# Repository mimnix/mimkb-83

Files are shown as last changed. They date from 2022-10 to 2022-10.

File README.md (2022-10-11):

# MIMKB-83: Fully 3D printed DIY ISO 75% handwired mechanical keyboard powered by Raspberry Pi Pico
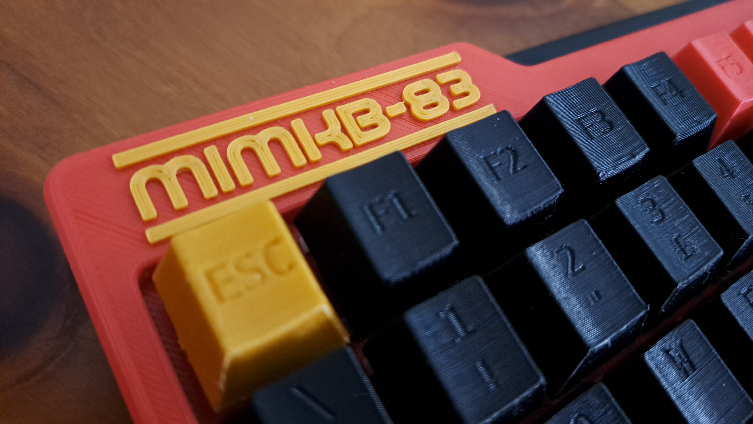
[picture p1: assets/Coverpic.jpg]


The keyboard is fully customizable, it supports layering, macros, dynamic sequences, and chords. The possibilities are endless. The project includes:

- Building instructions
- 3d model of the body of the keyboard
- 3d models of KeyV2 generated keycaps (default: ISO-ITA with Cherry profile)
- Wiring instructions
- Firmware source code for the Raspberry Pi Pico

## Features
The firmware is implemented to provide basic keyboard features and plus:

**Media keys**
- Fn + F1 = Mute audio
- Fn + F2 = Audio volume down
- Fn + F3 = Audio volume up

**Dynamic sequences (macros)**
- Fn + 1,2,...,0 = Select sequence slot
- Fn + F5 = Record sequence in the current slot
- Fn + F6 = Stop recording sequence in the current slot
- Fn + F7 = Play the sequence of the current slot

## Bill of materials and cost breakdown
You're supposed to have access to a 3D printer with some PLA spools. A PLA spool costs around 18-20€
For this build I've used:
- PLA plastic (18€)
- 90x Outemu Silent Peach linear switches (25€)
- Raspberry Pi Pico (7€)
- 200x 1N4148 Diodes (1,7€)
- 100x 8x2.5mm rubber feet (2€)
- Costar stabs (4,8€)
- Copper wire (2,7€)
- 12x M3x12mm screws (some cents)
- Some 22awg wire (some cents)
- Optional: Krytox GPL 205 lube because you love custom keyboards and lube switches and stabs, don't you?

**Total cost: 61,2€** and you will get a lot of remaining material available for other builds.

## Body parts
Navigate to the `model/body/STL` folder and print one copy of each file. You have 5 body parts in total: 2 pieces for the plate (`Top_left_iso` and `Top_right_iso`), 2 pieces for the housing (`Bottom_left` containing the microcontroller slot and `Bottom_right`), 
1 set of `Dowels` to keep all the pieces joined together and harden the structure. Import the files in your favorite slicer (Prusa slicer, Ultimaker Cura, etc...) and produce the gcode files. The prototype has been printed using the following settings:

- Printing material: PLA
- Standard quality (layer height 0.2mm, walls width 0.8mm with 2 perimetral lines, printing speed 50mm/s)
- Bed temperature: 60°C (it depends on the specific material)
- Extruder temperature: 200°C (it depends on the specific material)
- Infill: 20%
- 5mm of brim, around 13 lines just to avoid any warping effect
- no supports, they're not needed

Once all the parts are printed, glue and connect the two top half sectors and the two bottom half sectors, that's it.

## Keycaps
Navigate to the `model/body/keycaps/STL` folder and print everything. Prebuilt keycaps are for the 75% ISO-ITA layout, if you need advanced customization, please refer to the [advanced customizations](#advanced-customizations) section. You will find printable keycap groups with legends (filenames are pretty self-explanatory). You can use the same slicer configuration as the body parts, just consider placing the keycaps with the southern surface facing the bed plate, screenshot for reference:

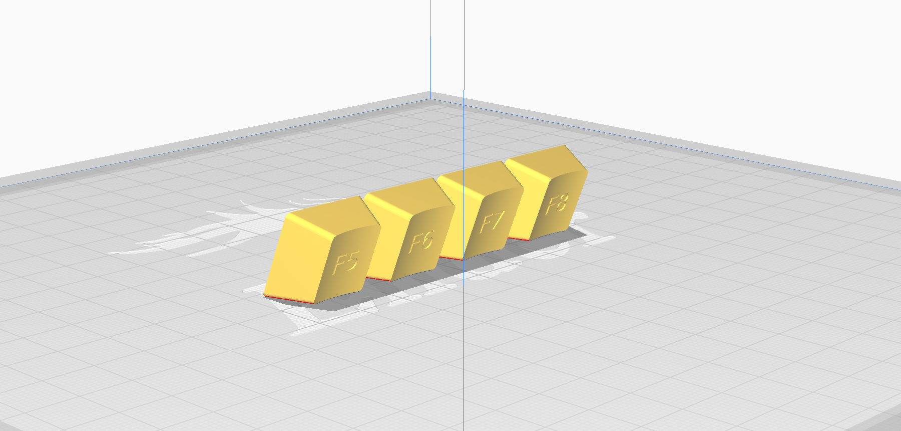
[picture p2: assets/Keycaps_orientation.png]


## Wiring instructions
Here comes the ~~boring~~ fun part. First thing first, take the 3d printed plate and snap your favorite mechanical switches into it.

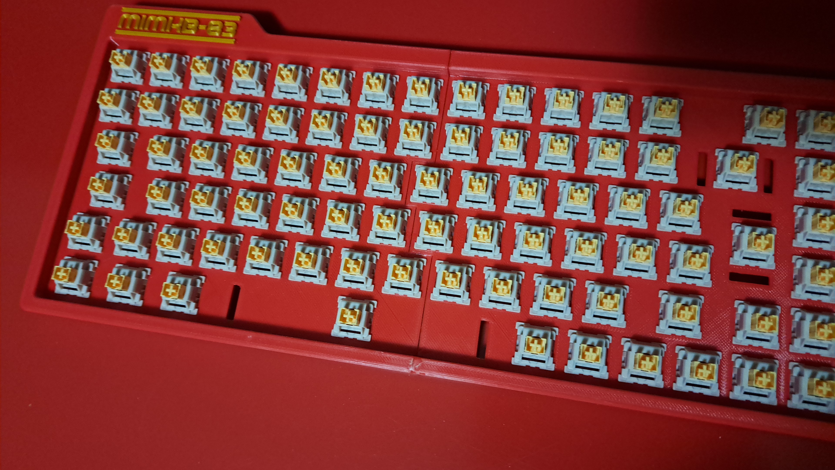
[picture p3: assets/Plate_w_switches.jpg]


Turn over the plate, take the diodes and bend'em from the cathode side in this way:

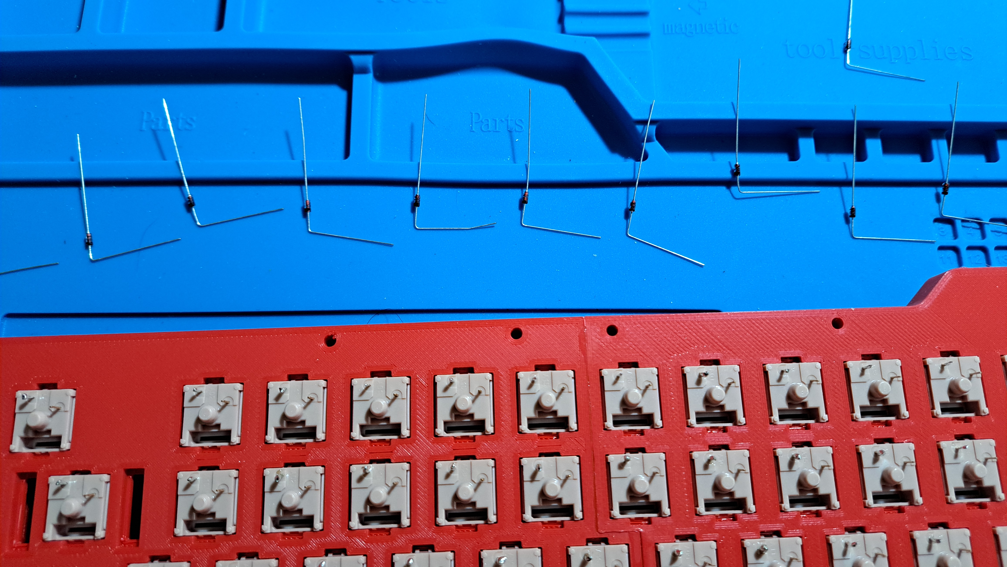
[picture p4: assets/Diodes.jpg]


Solder each anode to the leftmost pin of the switches, and the cathode to the next diode's cathode to create a row:

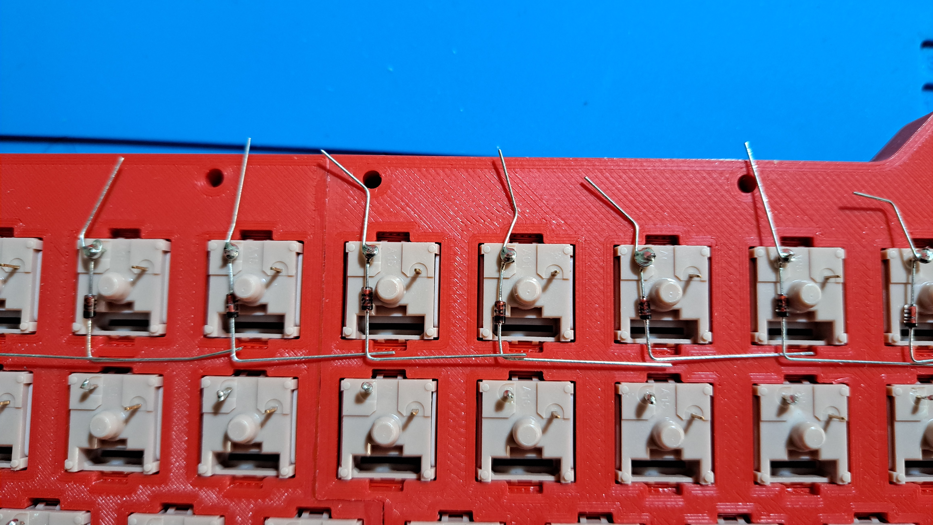
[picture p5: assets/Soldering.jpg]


Snap the exceeding metal terminals and everything will look like this:

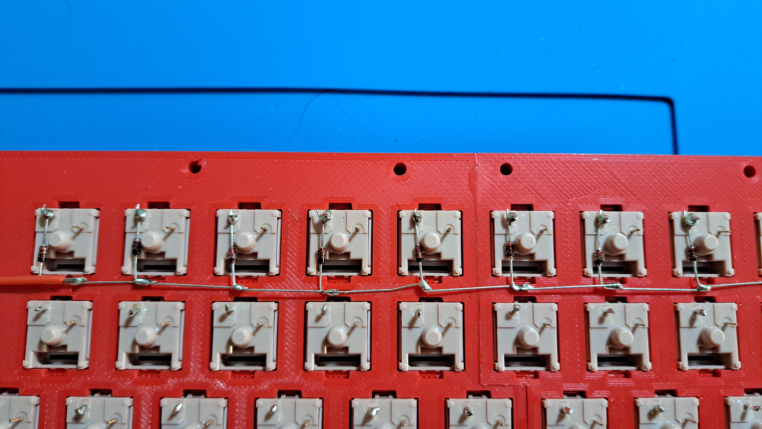
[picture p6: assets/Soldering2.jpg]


Repeat for all the rows and isolate them using electrical tape stripes. Then, solder the columns using some 0.5mm copper wire: connect the right pin of all the switches in the same column, like in the picture below:

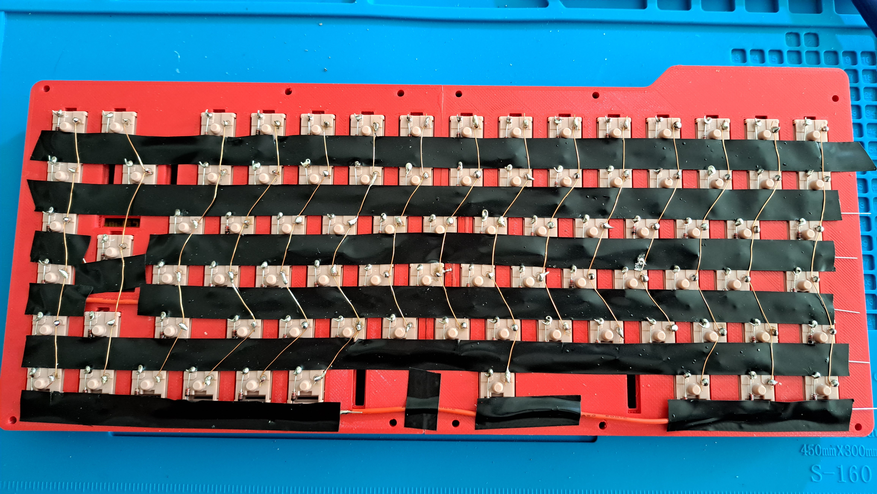
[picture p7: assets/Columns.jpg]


Now, time to connect the switch matrix to the Raspberry Pi Pico board according to the following wiring diagram:

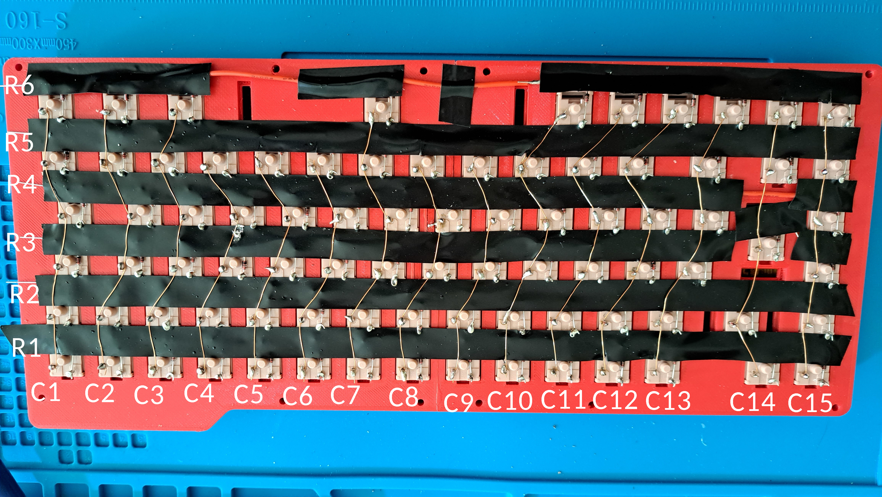
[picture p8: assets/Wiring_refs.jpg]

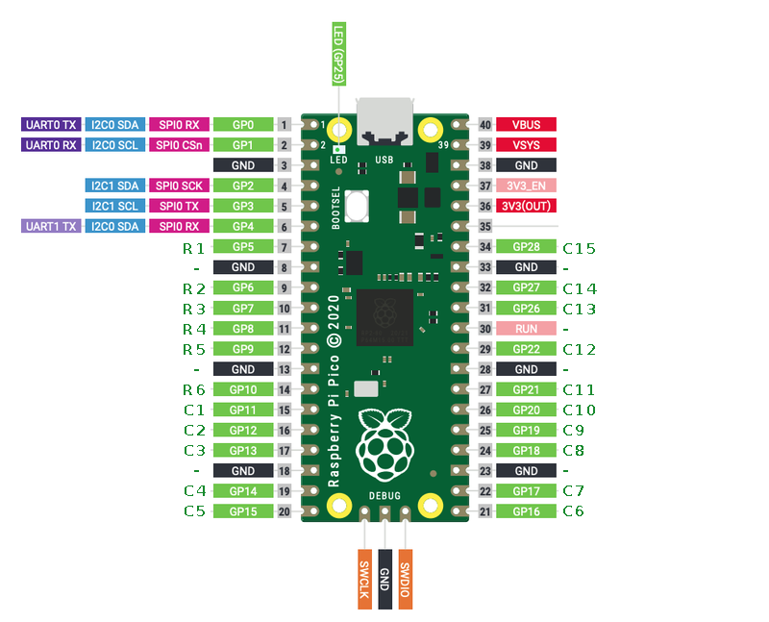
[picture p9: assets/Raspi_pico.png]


This is how it should look like:

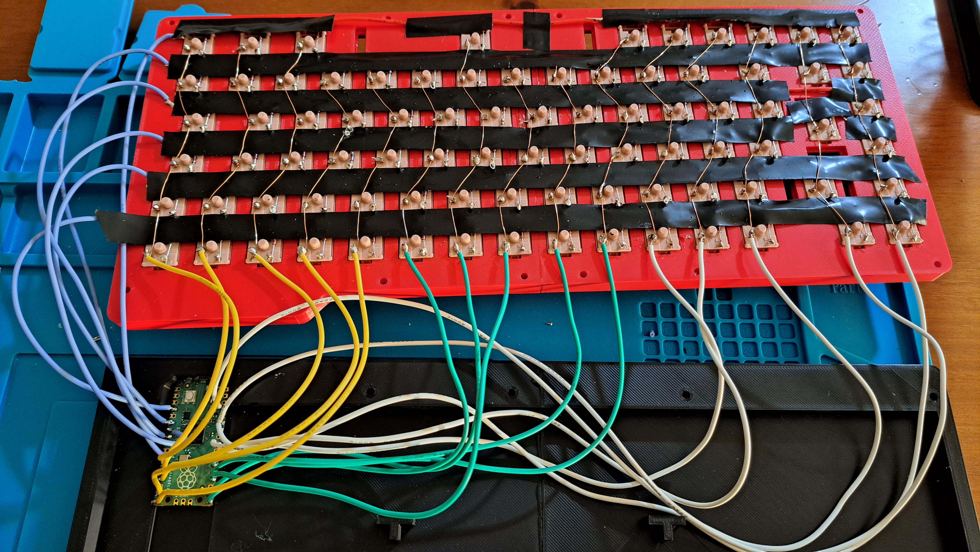
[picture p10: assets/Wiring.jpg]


And here's the PCB closeup:

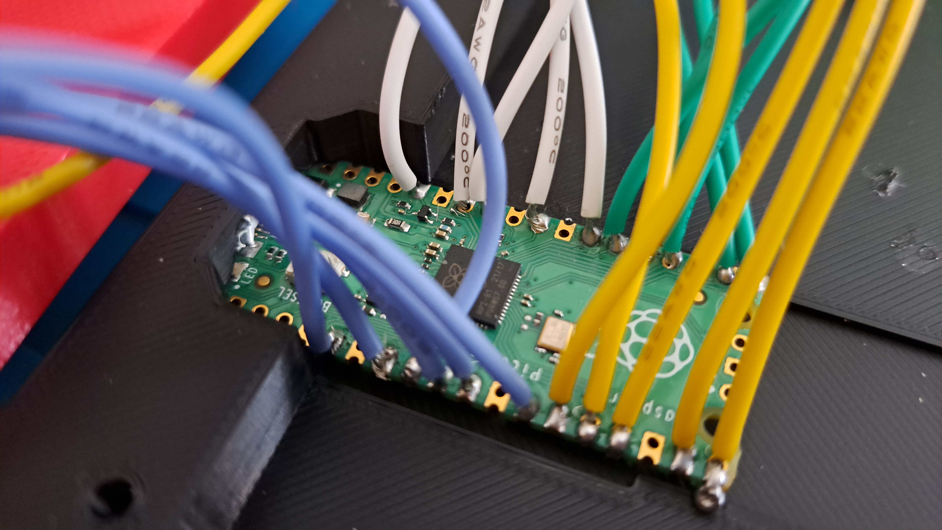
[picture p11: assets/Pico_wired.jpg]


Place the Raspberry Pi Pico in its slot, and fix it using a hot glue gun. The glue protects the cables and sticks the Raspberry pi pico in place. Close the keyboard and screw the plate and the housing together using 12mm M3 bolts, stick four 8x2.5mm rubber feet on the bottom surface of the keyboard snap the stabilizers in their slots, snap the keycaps on top of the switches and with the hardware you're pretty good to go.

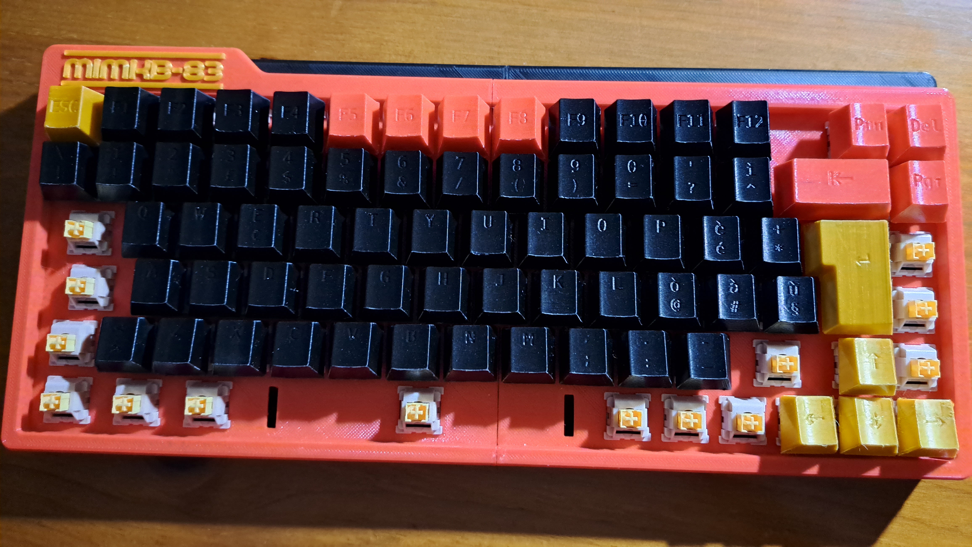
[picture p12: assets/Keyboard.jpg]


## Firmware
4 simple steps:
1. Connect the keyboard to the PC.
2. Install [CircuitPython](https://learn.adafruit.com/welcome-to-circuitpython/installing-circuitpython) version 7.0 or above in the Raspberry Pi Pico.
3. Install [KMK](https://github.com/KMKfw/kmk_firmware/blob/master/docs/Getting_Started.md) in the board.
4. Replace the `code.py` file of the board with the one provided in the directory `firmware` of this project.

**Happy typing!**

## Advanced customizations
You can customize pretty much everything, the possibilities are endless. Install OpenSCAD on your PC, open the file `model/keycaps/KeyV2/keys.scad`. It's the layout definition of Mimkb-83. From there, you can edit legends and every possible feature such as height, stems, profiles, and so on. The most important files are two:

- `model/keycaps/KeyV2/keys.scad` to edit the layout and the keyboard profile (default: cherry/GMK)
- `model/keycaps/KeyV2/settings.scad` to edit stem type (default: rounded cherry), support type, sizes, and all the physical aspects of the keycaps.

For more info about keyboard profiles, have a look at [keycaps.info](https://keycaps.info).

You can also modify the firmware according to the [KMK documentation](http://kmkfw.io/)

## Credits
This project is based on and inspired by the work of some makers and developers out there. They provided their code to the world. A deserved shoutout to:

- [SICK-68 keyboard](https://www.thingiverse.com/thing:3478494) by FedorSosnin
- [The Raspberry Pi Pico](https://www.raspberrypi.com/products/raspberry-pi-pico/) open hardware board by the Raspberry Pi Foundation
- [KMKfw](http://kmkfw.io/) the pythonic keyboard firmware
- Bob rsheldii's [KeyV2](https://github.com/rsheldiii/KeyV2), a parametric mechanical keycap library

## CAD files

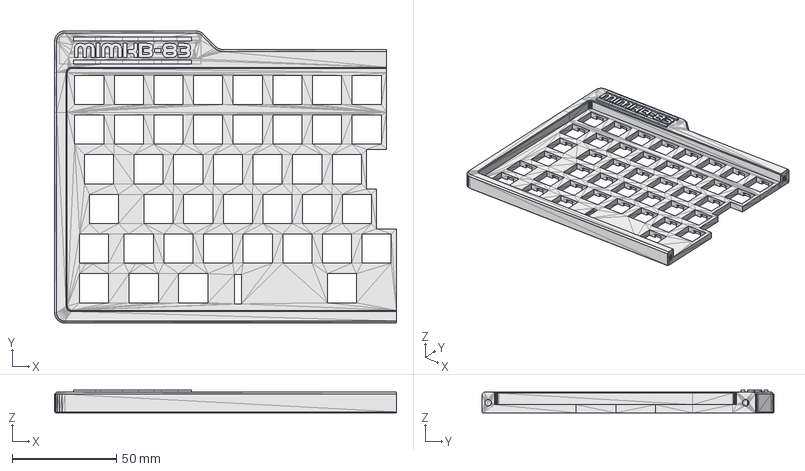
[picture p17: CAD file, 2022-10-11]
model/body/Mimboard.FCStd
164.3 x 140.4 x 11.0 mm

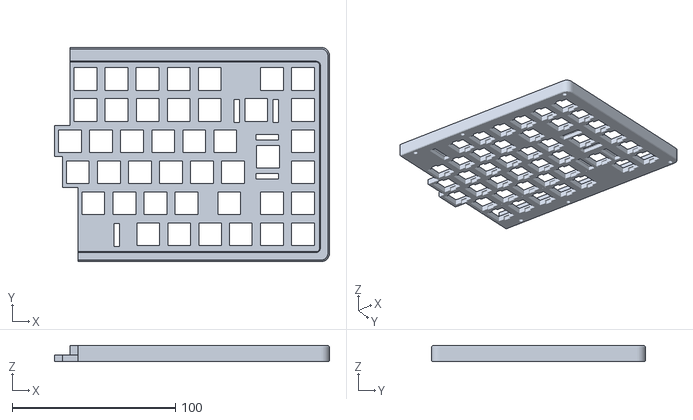
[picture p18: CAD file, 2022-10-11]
model/body/STL/Top_right_iso.stl
168.7 x 131.4 x 10.0

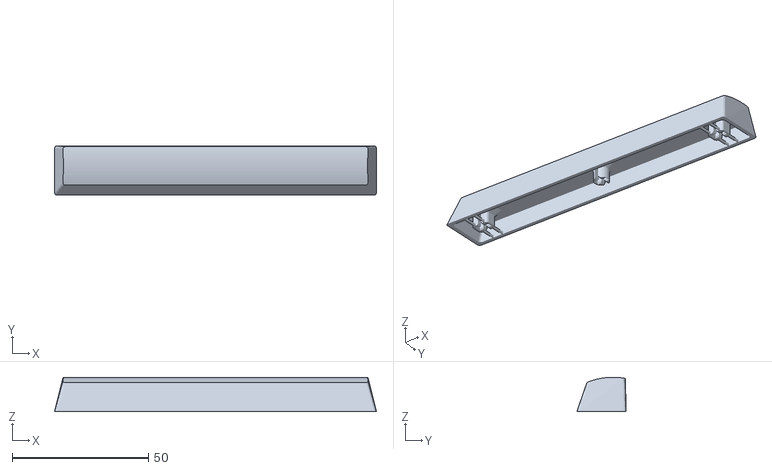
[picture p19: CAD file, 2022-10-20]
model/keycaps/STL/Spacebar.stl
118.2 x 18.2 x 12.6

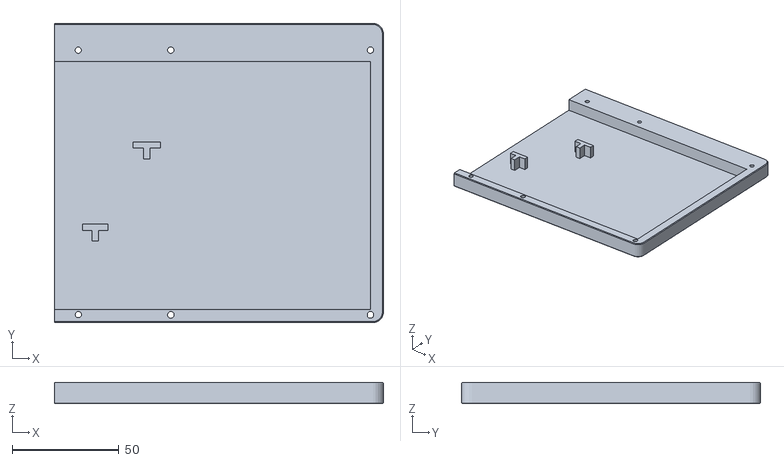
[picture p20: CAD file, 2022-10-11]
model/body/STL/Bottom_right.stl
154.3 x 140.4 x 10.0

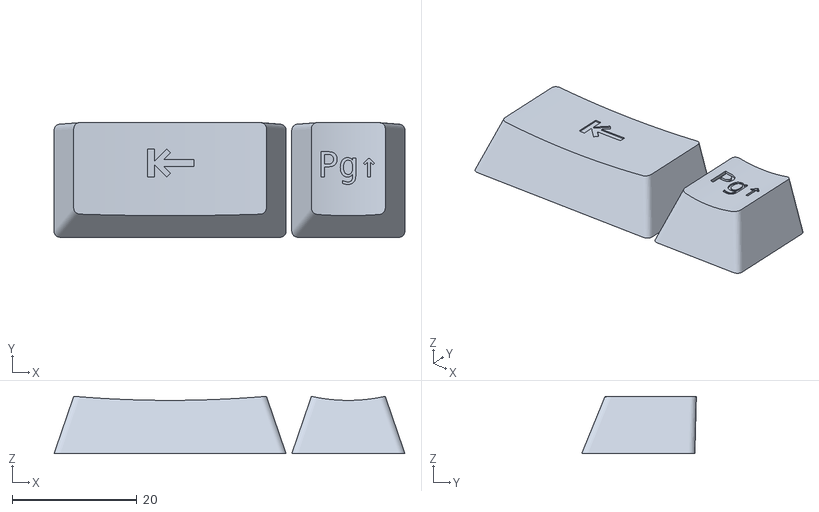
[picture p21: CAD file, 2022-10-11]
model/keycaps/STL/Keys Backspace PageUp.stl
56.3 x 18.4 x 9.20

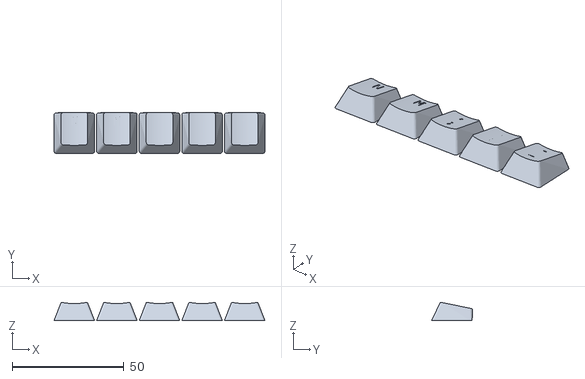
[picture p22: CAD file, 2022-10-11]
model/keycaps/STL/Keys row2 2of2.stl
94.4 x 18.3 x 8.10

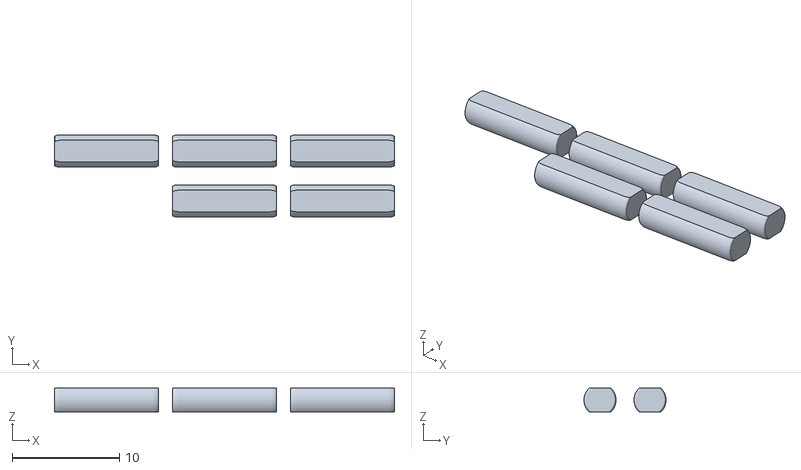
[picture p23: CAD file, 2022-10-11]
model/body/STL/Dowels.stl
31.7 x 7.66 x 2.21

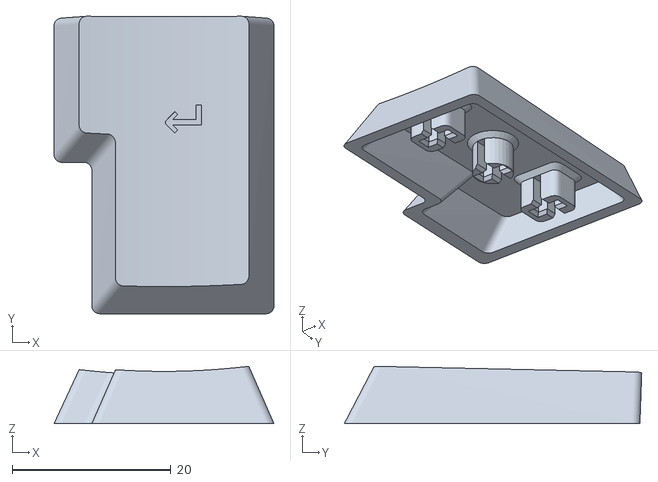
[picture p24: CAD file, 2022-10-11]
model/keycaps/STL/Keys Enter.stl
27.7 x 37.4 x 7.20

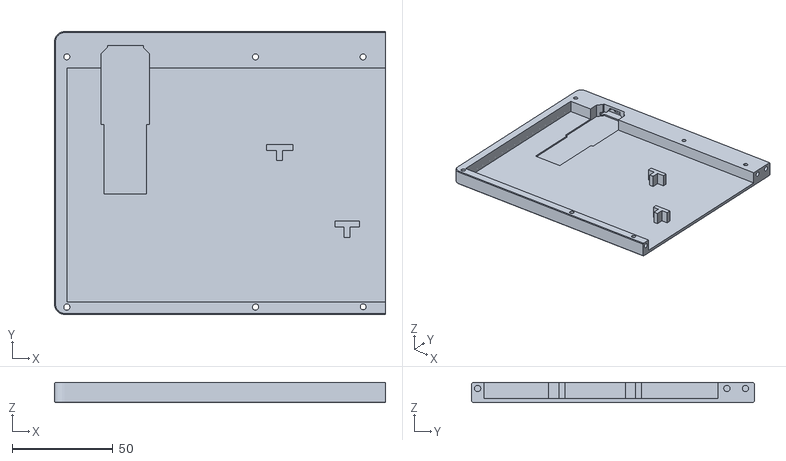
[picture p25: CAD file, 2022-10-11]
model/body/STL/Bottom_left.stl
164.3 x 140.4 x 10.0

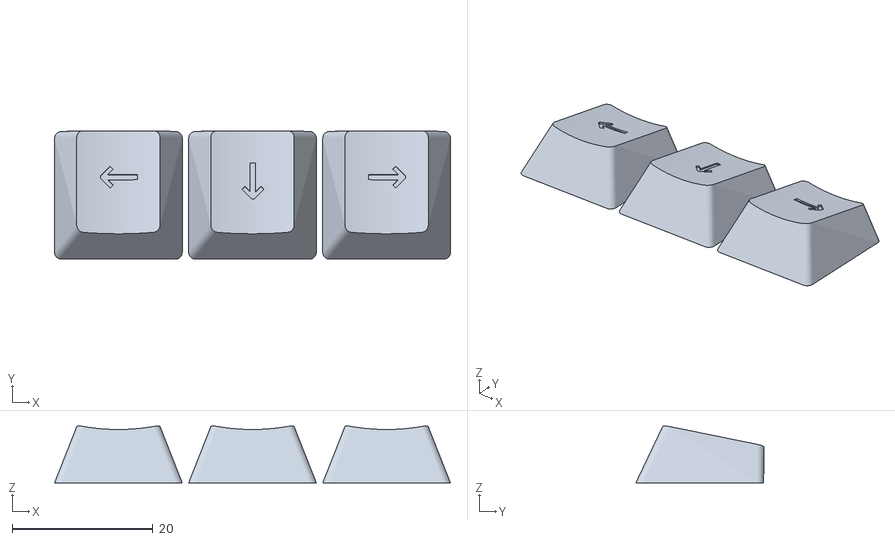
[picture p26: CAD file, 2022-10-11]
model/keycaps/STL/Keys Arrow Left Down Right.stl
56.3 x 18.3 x 8.10

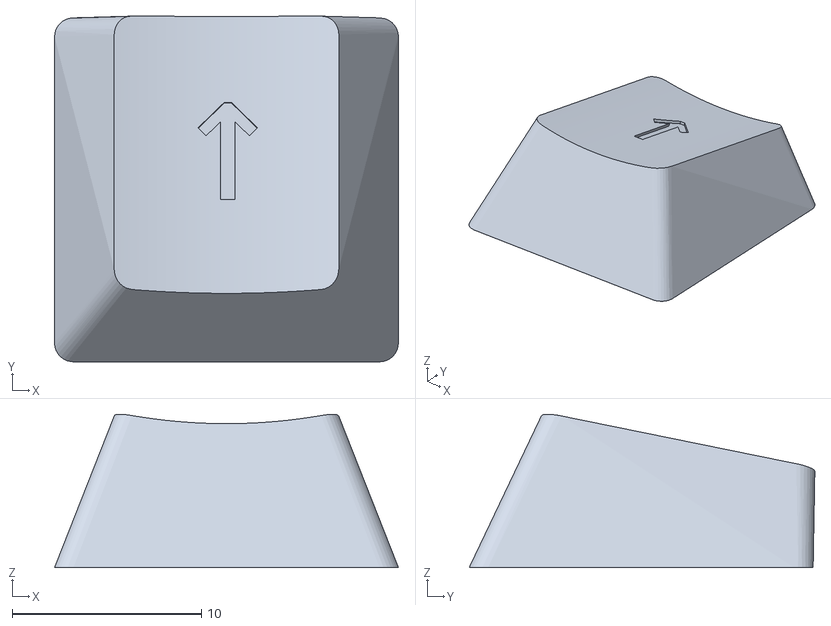
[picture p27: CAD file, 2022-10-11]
model/keycaps/STL/Keys Arrow Up.stl
18.2 x 18.3 x 8.10

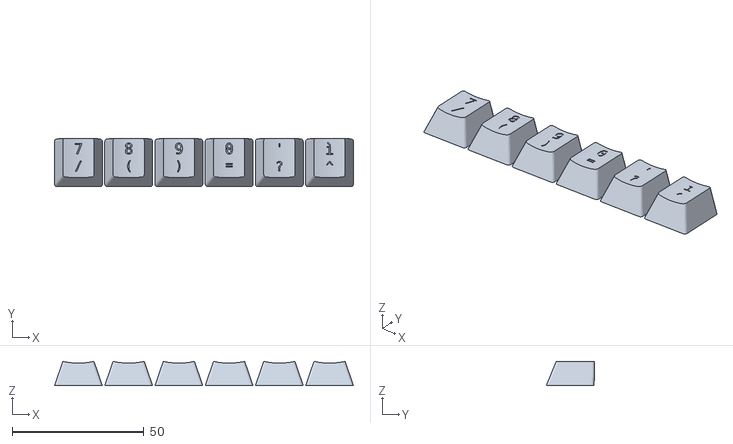
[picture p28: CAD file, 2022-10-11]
model/keycaps/STL/Keys row5 2of2.stl
113.4 x 18.4 x 9.20

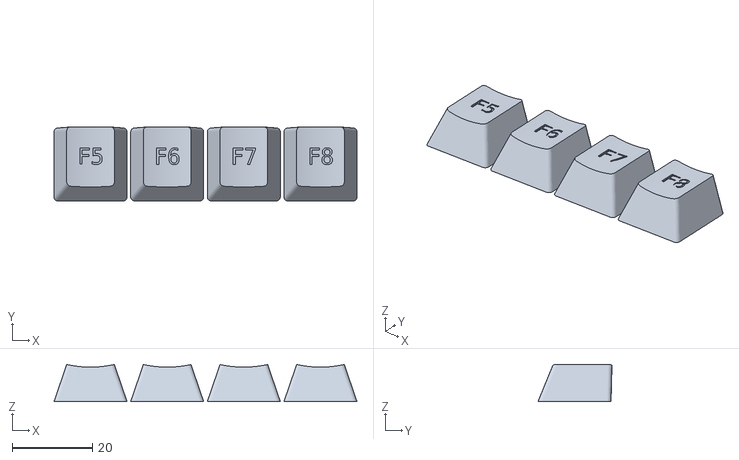
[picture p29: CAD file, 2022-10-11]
model/keycaps/STL/Keys F5-F8.stl
75.3 x 18.4 x 9.20

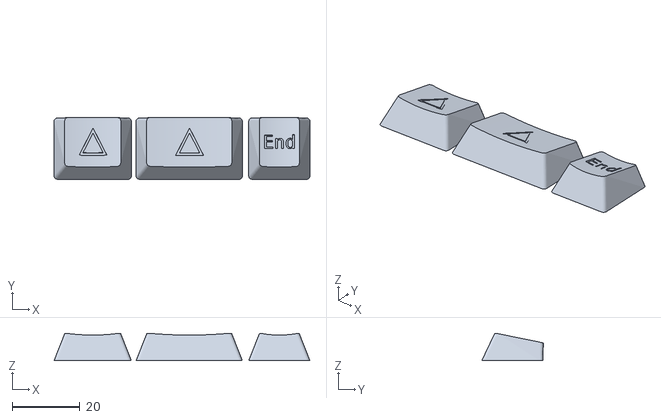
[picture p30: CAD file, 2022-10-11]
model/keycaps/STL/Keys Lshift Rshift End.stl
75.8 x 18.3 x 8.14

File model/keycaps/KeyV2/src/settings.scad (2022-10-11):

/* [Basic-Settings] */

// Length in units of key. A regular key is 1 unit; spacebar is usually 6.25
$key_length = 1.0; // Range not working in thingiverse customizer atm [1:0.25:16]

// What type of stem you want. Most people want Cherry.
$stem_type = "rounded_cherry";  // [cherry, alps, rounded_cherry, box_cherry, filled, disable]

// The stem is the hardest part to print, so this variable controls how much 'slop' there is in the stem
// if your keycaps stick in the switch raise this value
$stem_slop = 0.35; // Not working in thingiverse customizer atm [0:0.01:1]
// broke this out. if your keycaps are falling off lower this value. only works for cherry stems rn
$stem_inner_slop = 0.2;

// Font size used for text
$font_size = 6;

// Set this to true if you're making a spacebar!
$inverted_dish = false;

// change aggressiveness of double sculpting
// this is the radius of the cylinder the keytops are placed on
$double_sculpt_radius = 200;


// Support type. default is "flared" for easy FDM printing; bars are more realistic, and flat could be for artisans
$support_type = "flared"; // [flared, bars, flat, disable]

// Supports for the stem, as it often comes off during printing. Reccommended for most machines
$stem_support_type = "tines"; // [tines, brim, disabled]

// make legends outset instead of inset.
// broken off from artisan support since who wants outset legends?
$outset_legends = false;

/* [Key] */
// Height in units of key. should remain 1 for most uses
$key_height = 1.0;
// Keytop thickness, aka how many millimeters between the inside and outside of the top surface of the key
$keytop_thickness = 1;
// Wall thickness, aka the thickness of the sides of the keycap. note this is the total thickness, aka 3 = 1.5mm walls
$wall_thickness = 3;
// Radius of corners of keycap
$corner_radius = 1;
// Width of the very bottom of the key
$bottom_key_width = 18.16;
// Height (from the front) of the very bottom of the key
$bottom_key_height = 18.16;
// How much less width there is on the top. eg top_key_width = bottom_key_width - width_difference
$width_difference = 6;
// How much less height there is on the top
$height_difference = 4;
// How deep the key is, before adding a dish
$total_depth = 11.5;
// The tilt of the dish in degrees. divided by key height
$top_tilt = -6;
// the y tilt of the dish in degrees. divided by key width.
// for double axis sculpted keycaps and probably not much else
$top_tilt_y = 0;
// How skewed towards the back the top is (0 for center)
$top_skew = 1.7;

// how skewed towards the right the top is. unused, but implemented.
// for double axis sculpted keycaps and probably not much else
$top_skew_x = 0;

/* [Stem] */

// How far the throw distance of the switch is. determines how far the 'cross' in the cherry switch digs into the stem, and how long the keystem needs to be before supports can start. luckily, alps and cherries have a pretty similar throw. can modify to have stouter keycaps for low profile switches, etc
$stem_throw = 4;
// Diameter of the outside of the rounded cherry stem
$rounded_cherry_stem_d = 5.5;


// How much higher the stem is than the bottom of the keycap.
// Inset stem requires support but is more accurate in some profiles
// can be negative to make outset stems!
$stem_inset = 0;
// How many degrees to rotate the stems. useful for sideways keycaps, maybe
$stem_rotation = 0;

/* [Shape] */

// Key shape type, determines the shape of the key. default is 'rounded square'
$key_shape_type = "rounded_square";
// ISO enter needs to be linear extruded NOT from the center when not using skin. this tells the program how far up 'not from the center' is
$linear_extrude_height_adjustment = 0;
// How many slices will be made, to approximate curves on corners. Leave at 1 if you are not curving corners
// If you're doing fancy bowed keycap sides, this controls how many slices you take
$height_slices = 1;

/* [Dish] */

// What type of dish the key has. note that unlike stems and supports a dish ALWAYS gets rendered.
$dish_type = "cylindrical"; // [cylindrical, spherical, sideways cylindrical, old spherical, disable]
// How deep the dish 'digs' into the top of the keycap. this is max depth, so you can't find the height from total_depth - dish_depth. besides the top is skewed anyways
$dish_depth = 1;
// How skewed in the x direction the dish is
$dish_skew_x = 0;
// How skewed in the y direction (height) the dish is
$dish_skew_y = 0;


$dish_offset_x = 0;

// If you need the dish to extend further, you can 'overdraw' the rectangle it will hit. this was mostly for iso enter and should be deprecated
$dish_overdraw_width = 0;
// Same as width but for height
$dish_overdraw_height = 0;

/* [Misc] */
// There's a bevel on the cherry stems to aid insertion / guard against first layer squishing making a hard-to-fit stem.
$cherry_bevel = true;

// How tall in mm the stem support is, if there is any. stem support sits around the keystem and helps to secure it while printing.
$stem_support_height = .8;
// Font used for text
$font="DejaVu Sans Mono:style=Book";
// Whether or not to render fake keyswitches to check clearances
$clearance_check = false;
// Should be faster, also required for concave shapes

// what kind of extrusion we use to create the keycap. "hull" is standard, "linear extrude" is legacy, "skin" is new and not well supported.
$hull_shape_type = "hull"; // ["hull", "linear extrude", "skin"]

// This doesn't work very well, but you can try
$rounded_key = false;
//minkowski radius. radius of sphere used in minkowski sum for minkowski_key function. 1.75 for G20
$minkowski_radius = .33;

/* [Features] */

//insert locating bump
$key_bump = false;
//height of the location bump from the top surface of the key
$key_bump_depth = 0.5;
//distance to move the bump from the front edge of the key
$key_bump_edge = 0.4;

/* [Hidden] */

// set this to true if you are making double sculpted keycaps
$double_sculpted = false;

//list of legends to place on a key format: [text, halign, valign, size]
//halign = "left" or "center" or "right"
//valign = "top" or "center" or "bottom"
// Currently does not work with thingiverse customizer, and actually breaks it
$legends = [];

//list of front legends to place on a key format: [text, halign, valign, size]
//halign = "left" or "center" or "right"
//valign = "top" or "center" or "bottom"
// Currently does not work with thingiverse customizer, and actually breaks it
$front_legends = [];

// print legends on the front of the key instead of the top
$front_print_legends = false;

// how recessed inset legends / artisans are from the top of the key
$inset_legend_depth = 0.2;

// Dimensions of alps stem
$alps_stem = [4.45, 2.25];

// Dimensions of choc stem
$choc_stem = [1.2, 3];

// Enable stabilizer stems, to hold onto your cherry or costar stabilizers
$stabilizer_type = "costar_stabilizer"; // [costar_stabilizer, cherry_stabilizer, disable]

// Ternaries are ONLY for customizer. they will NOT work if you're using this in
// OpenSCAD. you should use stabilized(), openSCAD customizer,
// or set $stabilizers directly
// Array of positions of stabilizers
$stabilizers = $key_length >= 6 ? [[-50, 0], [50, 0]] : $key_length >= 2 ? [[-12,0],[12,0]] : [];

// Where the stems are in relation to the center of the keycap, in units. default is one in the center
// Shouldn't work in thingiverse customizer, though it has been...
$stem_positions = [[0,0]];

// colors
$primary_color = [.2667,.5882,1];
$secondary_color = [.4412, .7, .3784];
$tertiary_color = [1, .6941, .2];
$quaternary_color = [.4078, .3569, .749];
$warning_color = [1,0,0, 0.15];

// how many facets circles will have when used in these features
$minkowski_facets = 30;
$shape_facets =30;



// "flat" / "dished" / "disable"
$inner_shape_type = "flat";

// When sculpting sides using sculpted_square, how much in should the tops come
$side_sculpting_factor = 4.5;
// When sculpting corners, how much extra radius should be added
$corner_sculpting_factor = 1;
// When doing more side sculpting corners, how much extra radius should be added
$more_side_sculpting_factor = 0.4;

// 3d surface functions (still in beta)

// 3d surface settings
// unused for now
$3d_surface_size = 20;
// resolution in each axis. 10 = 10 divisions per x/y = 100 points total. 
// 5 = 20 divisions per x/y
$3d_surface_step = 1;

// monotonically increasing function that distributes the points of the surface mesh
// only for polar_3d_surface right now
// if it's linear it's a grid. sin(dim) * size concentrates detail around the edges
sinusoidal_surface_distribution = function(dim,size) sin(dim) * size;
linear_surface_distribution = function(dim,size) sin(dim) * size;

$surface_distribution_function = linear_surface_distribution;

// the function that actually determines what the surface is.
// feel free to override, the last one wins
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

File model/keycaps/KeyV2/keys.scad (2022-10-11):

include <./includes.scad>

//ROW FN
legends_row_FN = [
 ["ESC"], ["F1"], ["F2"], ["F3"], ["F4"], ["F5"], ["F6"], ["F7"], ["F8"], ["F9"], ["F10"], ["F11"], ["F12"], ["Prn"], ["Del"]
];

for(y = [0:len(legends_row_FN)-1]){
    translate_u(y,1) cherry_row(1) legend(legends_row_FN[y][0], position=[0,0], size=4) key();
}

//ROW 5
legends_row_5 = [
 ["\\","|"], ["1","!"], ["2","\""], ["3","£"], ["4","$"], ["5","%"], ["6","&"], ["7","/"], ["8","("], ["9",")"], ["0","="], ["'","?"], ["ì","^"]
];
for(y = [0:len(legends_row_5)-1]){
    translate_u(y) cherry_row(1) legend(legends_row_5[y][0], position=[0,-0.8], size=4) legend(legends_row_5[y][1], position=[0,0.8], size=3.5) key();
}
u(2) translate_u(len(legends_row_5)+0.5) cherry_row(1) legend("⇤", size=10) key();
translate_u(len(legends_row_5)+2) cherry_row(1) legend("Pg↑", size=4) key();

//ROW 4
u(1.5) translate_u(0.25,-1) cherry_row(2) legend("↹",size=10) key();
legends_row_4 = [
 ["Q"], ["W"], ["E","€"], ["R"], ["T"], ["Y"], ["U"], ["I"], ["O"], ["P"], ["è","é"], ["+","*"]
];
for(y = [0:len(legends_row_4)-1]){
    if(len(legends_row_4[y]) == 2){
        translate_u(y+1.5,-1) cherry_row(2) legend(legends_row_4[y][0], position=[0,-0.8], size=4) legend(legends_row_4[y][1], position=[0,0.8], size=3.5) key();
    }
    else{
        translate_u(y+1.5,-1) cherry_row(2) legend(legends_row_4[y][0], position=[0,-0.8], size=4) key();
    }
}
//cherry_row(2) translate_u(len(legends_row_4)+1.88,-1.5) legend("↵", size=6, position=[0,-0.4]) iso_enter() key();
translate_u(len(legends_row_4)+3, -1) cherry_row(2) legend("Pg↓", size=4) key();


//ROW 3
u(1.70) translate_u(0.35,-2) cherry_row(3) legend("▲",size=10) key();
legends_row_3 = [
 ["A"], ["S"], ["D"], ["F"], ["G"], ["H"], ["J"], ["K"], ["L"], ["ò","@"], ["à","#"], ["ù","§"]
];
for(y = [0:len(legends_row_3)-1]){
    if(len(legends_row_3[y]) == 2){
        translate_u(y+1.7,-2) cherry_row(3) legend(legends_row_3[y][0], position=[0,-0.8], size=4) legend(legends_row_3[y][1], position=[0,0.8], size=3.5) key();
    }
    else{
        translate_u(y+1.7,-2) cherry_row(3) legend(legends_row_3[y][0], position=[0,-0.8], size=4) key();
    }
}
translate_u(len(legends_row_3)+3,-2) cherry_row(3) legend("Hom", position=[0,0], size=4) key();

//ROW 2
u(1.25) translate_u(0.12,-3) cherry_row(4) legend("△",size=10) key();
legends_row_2 = [
 ["<",">"], ["Z"], ["X"], ["C"], ["V"], ["B"], ["N"], ["M"], [",",";"], [".",":"], ["-","_"]
];
for(y = [0:len(legends_row_2)-1]){
    if(len(legends_row_2[y]) == 2){
        translate_u(y+1.25,-3) cherry_row(4) legend(legends_row_2[y][0], position=[0,-0.8], size=4) legend(legends_row_2[y][1], position=[0,0.8], size=3.5) key();
    }
    else{
        translate_u(y+1.25,-3) cherry_row(4) legend(legends_row_2[y][0], position=[0,-0.8], size=4) key();
    }
}
u(1.7) translate_u(len(legends_row_2)+2,-3) cherry_row(4) legend("△", size=10) key();
translate_u(14.75,-3) cherry_row(4) legend("↑",size=7) key();
translate_u(15.75,-3) cherry_row(4) legend("End",size=4) key();


//ROW 1
u(1.25) translate_u(0.25,-4) cherry_row(5) legend("ctrl",size=4) key();
u(1.25) translate_u(1.75,-4) cherry_row(5) legend("☢",size=10) key();
u(1.25) translate_u(3.25,-4) cherry_row(5) legend("alt",size=4) key();
translate_u(7.12,-4) legend("PROTOTYPE 0",size=4) spacebar() key();
translate_u(10.75,-4) cherry_row(5) legend("Alt",size=4) key();
translate_u(11.75,-4) cherry_row(5) legend("Fn",size=4) key();
translate_u(12.75,-4) cherry_row(5) legend("Ctr",size=4) key();
translate_u(13.75,-4) cherry_row(5) legend("←",size=7) key();
translate_u(14.75,-4) cherry_row(5) legend("↓",size=7) key();
translate_u(15.75,-4) cherry_row(5) legend("→",size=7) key();

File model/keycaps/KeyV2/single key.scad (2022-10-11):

// the point of this file is to be a sort of DSL for constructing keycaps.
// when you create a method chain you are just changing the parameters
// key.scad uses, it doesn't generate anything itself until the end. This
// lets it remain easy to use key.scad like before (except without key profiles)
// without having to rely on this file. Unfortunately that means setting tons of
// special variables, but that's a limitation of SCAD we have to work around

include <./includes.scad>


// example key
//dcs_row(5) legend("⇪", size=9) key();
//dcs_row(4) legend("€", size=9) key();

/*for (x = [0:1:3]){
    translate_u(0, -x) dcs_row(5) legend("q") key();
}*/

// example row
/* for (x = [0:1:4]) {
  translate_u(0,-x) dcs_row(x) key();
} */


//ROW 3
legends_row_3 = [
 ["A"], ["S"], ["D"], ["F"], ["G"], ["H"], ["J"], ["K"], ["L"], ["ò","@"], ["à","#"], ["ù","§"]
];


cherry_row(1) legend(legends_row_3[9][0], position=[0,-0.8], size=4) legend(legends_row_3[9][1], position=[0,0.8], size=3.5) key();

//translate_u(2) cherry_row(4) rshift() legend("Espresso", size=4) key();


/*
translate_u(0, -1) dcs_row(5) legend("\\", size=5) key();
translate_u(0, -2) dcs_row(1) legend("1", size=5) key();
translate_u(0, -3) dcs_row(2) legend("Q", size=5) key();
translate_u(0, -4) dcs_row(3) legend("A", size=5) key();
translate_u(0, -5) dcs_row(4) legend("Z", size=5) key();
translate_u(0, -6) dcs_row(1) legend("Z", size=5) key();*/

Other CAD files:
model/body/STL/Top_left_iso.stl
model/keycaps/STL/Keys Alt Fn Ctrl.stl
model/keycaps/STL/Keys row2 1of2.stl
model/keycaps/STL/Keys row3 1of2.stl
model/keycaps/KeyV2/src/constants.scad
model/keycaps/KeyV2/customizer.scad
model/keycaps/KeyV2/customizer_base.scad
model/keycaps/KeyV2/examples/legends.scad
model/keycaps/KeyV2/examples/multimaterial_key_top.scad
model/keycaps/KeyV2/examples/multimaterial_legend.scad
model/keycaps/KeyV2/examples/plate_generation.scad
model/keycaps/KeyV2/examples/print_keycaps_on_their_side.scad
model/keycaps/KeyV2/examples/sa_ergo.scad
model/keycaps/KeyV2/examples/single_extruder_multimaterial_legends.scad
model/keycaps/KeyV2/includes.scad
model/keycaps/KeyV2/key_mold.scad
model/keycaps/KeyV2/model_base.scad
model/keycaps/KeyV2/src/dishes.scad
model/keycaps/KeyV2/src/dishes/3d_surface.scad
model/keycaps/KeyV2/src/dishes/cylindrical.scad
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

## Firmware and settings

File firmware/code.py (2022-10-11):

import board

from kmk.kmk_keyboard import KMKKeyboard
from kmk.keys import KC
from kmk.scanners import DiodeOrientation
from kmk.extensions.LED import LED
from kmk.extensions.led import AnimationModes
from kmk.extensions.international import International
from kmk.modules.layers import Layers
from kmk.extensions.media_keys import MediaKeys
from kmk.modules.dynamic_sequences import DynamicSequences

keyboard = KMKKeyboard()

keyboard.col_pins = (board.GP11, board.GP12, board.GP13, board.GP14, board.GP15, board.GP16, board.GP17, board.GP18, board.GP19, board.GP20, board.GP21, board.GP22, board.GP26, board.GP27, board.GP28)
keyboard.row_pins = (board.GP5, board.GP6, board.GP7, board.GP8, board.GP9, board.GP10)
keyboard.diode_orientation = DiodeOrientation.COL2ROW

#LED
led_ext = LED(led_pin=[board.GP25])
keyboard.extensions.append(led_ext)

#Suppport for international keys and media keys
keyboard.extensions.append(International())
keyboard.extensions.append(MediaKeys())

#Support for layers
keyboard.modules.append(Layers())
FNLAYER = KC.MO(1)

#Support for dynamic dynamic_sequences
dynamicSequences = DynamicSequences(
    slots=10, # The number of sequence slots to use
    timeout=60000,  # Maximum time to spend in record or config mode before stopping automatically, milliseconds
    key_interval=0,  # Milliseconds between key events while playing
    use_recorded_speed=False  # Whether to play the sequence at the speed it was typed
)
keyboard.modules.append(dynamicSequences)

keyboard.keymap = [
    [KC.ESCAPE, KC.F1, KC.F2, KC.F3, KC.F4, KC.F5, KC.F6, KC.F7, KC.F8, KC.F9, KC.F10, KC.F11, KC.F12, KC.PSCREEN, KC.DELETE,
     KC.GRAVE, KC.N1, KC.N2, KC.N3, KC.N4, KC.N5, KC.N6, KC.N7, KC.N8, KC.N9, KC.N0, KC.MINUS, KC.EQUAL, KC.BSPACE, KC.PGUP,
     KC.TAB, KC.Q, KC.W, KC.E, KC.R, KC.T, KC.Y, KC.U, KC.I, KC.O, KC.P, KC.LBRC, KC.RBRC, KC.ENTER, KC.PGDOWN,
     KC.CAPSLOCK, KC.A, KC.S, KC.D, KC.F, KC.G, KC.H, KC.J, KC.K, KC.L, KC.SCOLON, KC.QUOTE, KC.NUHS, KC.NO, KC.HOME,
     KC.LSHIFT, KC.NUBS, KC.Z, KC.X, KC.C, KC.V, KC.B, KC.N, KC.M, KC.COMMA, KC.DOT, KC.SLASH, KC.RSHIFT, KC.UP, KC.END,
     KC.LCTRL, KC.LGUI, KC.LALT, KC.NO, KC.NO, KC.NO, KC.SPACE, KC.NO, KC.NO, KC.RALT, FNLAYER, KC.RCTRL, KC.LEFT, KC.DOWN, KC.RIGHT] ,

    [KC.NO, KC.MUTE, KC.VOLD, KC.VOLU, KC.F4, KC.RECORD_SEQUENCE(), KC.STOP_SEQUENCE(), KC.PLAY_SEQUENCE(), KC.F8, KC.F9, KC.F10, KC.F11, KC.F12, KC.PSCREEN, KC.DELETE,
     KC.GRAVE, KC.SET_SEQUENCE(0), KC.SET_SEQUENCE(1), KC.SET_SEQUENCE(2), KC.SET_SEQUENCE(3), KC.SET_SEQUENCE(4), KC.SET_SEQUENCE(5), KC.SET_SEQUENCE(6), KC.SET_SEQUENCE(7), KC.SET_SEQUENCE(8), KC.SET_SEQUENCE(9), KC.MINUS, KC.EQUAL, KC.BSPACE, KC.PGUP,
     KC.TAB, KC.Q, KC.W, KC.E, KC.R, KC.T, KC.Y, KC.U, KC.I, KC.O, KC.P, KC.LBRC, KC.RBRC, KC.ENTER, KC.PGDOWN,
     KC.CAPSLOCK, KC.A, KC.S, KC.D, KC.F, KC.G, KC.H, KC.J, KC.K, KC.L, KC.SCOLON, KC.QUOTE, KC.NUHS, KC.NO, KC.HOME,
     KC.LSHIFT, KC.NUBS, KC.Z, KC.X, KC.C, KC.V, KC.B, KC.N, KC.M, KC.COMMA, KC.DOT, KC.SLASH, KC.RSHIFT, KC.UP, KC.END,
     KC.LCTRL, KC.LGUI, KC.LALT, KC.NO, KC.NO, KC.NO, KC.SPACE, KC.NO, KC.NO, KC.RALT, KC.TRNS, KC.RCTRL, KC.LEFT, KC.DOWN, KC.RIGHT]
]

if __name__ == '__main__':
    keyboard.go()
